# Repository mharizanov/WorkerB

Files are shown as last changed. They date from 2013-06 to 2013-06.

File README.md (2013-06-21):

WorkerB
=======

This is my latest project, the “Worker Bee”. It is an ATMega32U4-based Arduino compatible board running at 8Mhz, 
specially designed for low-power battery operation. There is a slot on the board to fit a 2.4Ghz nRF24L01 breakout 
module (not included, optional); Power to that slot is controlled via a MOSFET, so that the MCU is in control and 
can power the nRF24L01 whenever/if necessary and save power.

The board can be powered via a single AAA battery using an optional LTC3525 boost regulator, a CR2032 battery or 
any other 2.6-5.5V source (via the on-board MCP1700 for voltages >3.3V or directly at the VCC in)

http://harizanov.com/product/workerb/

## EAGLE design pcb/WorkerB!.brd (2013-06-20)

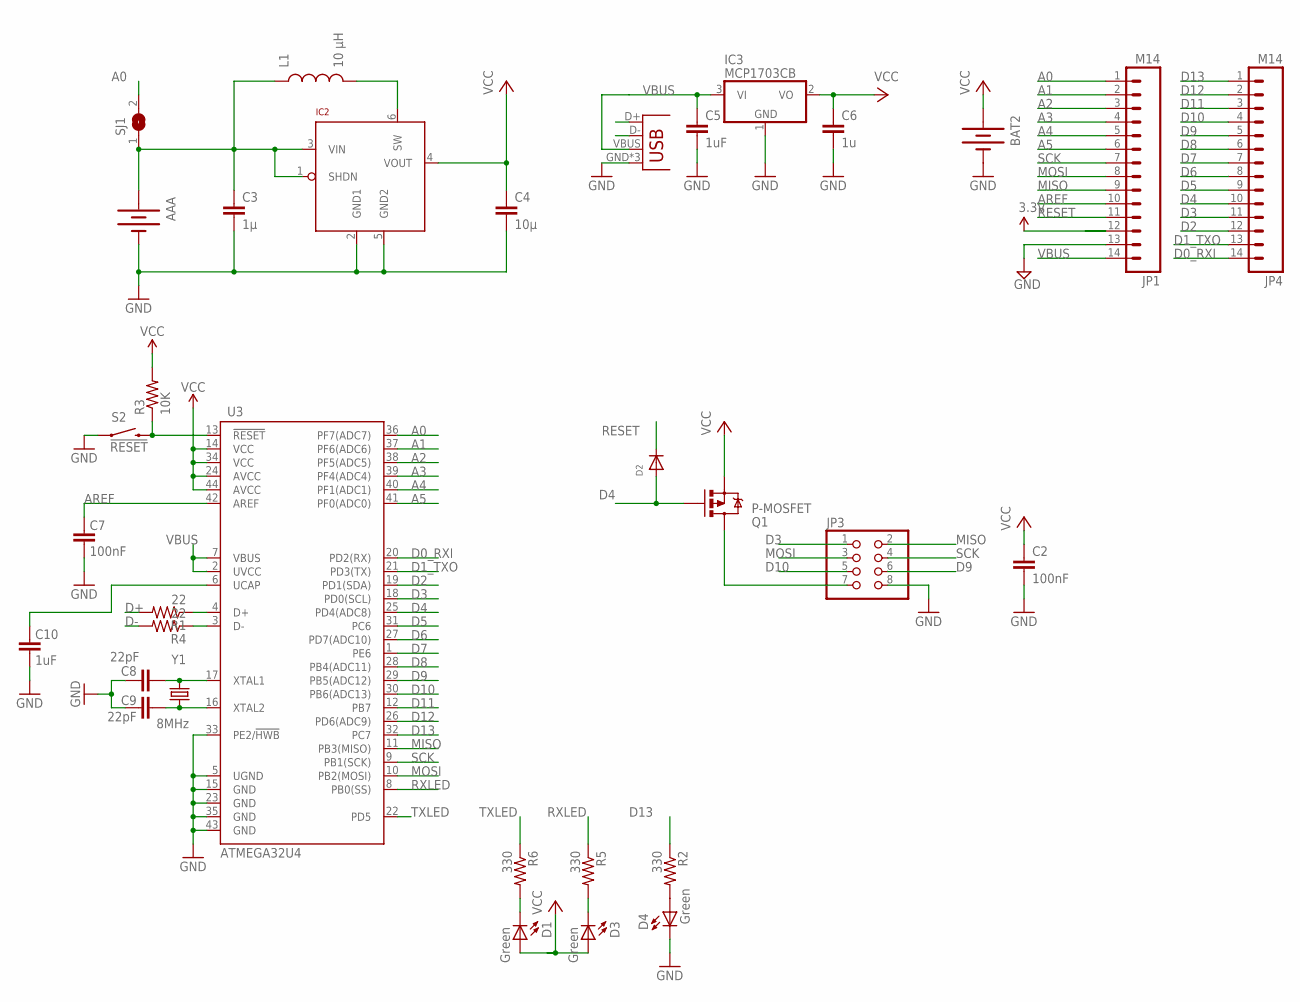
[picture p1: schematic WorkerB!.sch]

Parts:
AAA: BATTERYAAA-JL; BATTERY-AAA-JL
BAT2: BATTERY20PTH; BATTCOM_20MM_PTH
C2: 100nF; C0603K
C3: 1µ; 0603-CAP
C4: 10µ; 0805
C5: 1uF; C0603K
C6: 1u; C0603K
C7: 100nF; 0402-CAP
C8, C9: 22pF; 0402-CAP
C10: 1uF; 0402-CAP
D1, D3, D4: Green; LED-0603
D2: DIODESOD-323F; SOD-323F
IC2: LTC3525; SC70
IC3: MCP1703CB; SOT23
JP1, JP4: M14; 1X14
JP2: USB-MICROB
JP3: PINHD-2X4; 2X04
L1: 10 µH; 1210
Q1: P-MOSFET; SOT23
R1, R4: 22; 0402-RES
R2, R5, R6: 330; 0402-RES
R3: 10K; 0402-RES
S2: !RESET; TACTILE_SWITCH_SMD
SJ1: SJ
U3: ATMEGA32U4; QFN-44-NOPAD
Y1: 8MHz; CRYSTAL-SMD-5X3

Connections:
A0: JP1.1, SJ1.2, U3.36 (PF7(ADC7))
A1: JP1.2, U3.37 (PF6(ADC6))
A2: JP1.3, U3.38 (PF5(ADC5))
A3: JP1.4, U3.39 (PF4(ADC4))
A4: JP1.5, U3.40 (PF1(ADC1))
A5: JP1.6, U3.41 (PF0(ADC0))
AREF: C7.2, JP1.10, U3.42 (AREF)
D0_RXI: JP4.14, U3.20 (PD2(RX))
D1_TXO: JP4.13, U3.21 (PD3(TX))
D2: JP4.12, U3.19 (PD1(SDA))
D3: JP3.1, JP4.11, U3.18 (PD0(SCL))
D4: D2.A, JP4.10, Q1.1 (G), U3.25 (PD4(ADC8))
D5: JP4.9, U3.31 (PC6)
D6: JP4.8, U3.27 (PD7(ADC10))
D7: JP4.7, U3.1 (PE6)
D8: JP4.6, U3.28 (PB4(ADC11))
D9: JP3.6, JP4.5, U3.29 (PB5(ADC12))
D10: JP3.5, JP4.4, U3.30 (PB6(ADC13))
D11: JP4.3, U3.12 (PB7)
D12: JP4.2, U3.26 (PD6(ADC9))
D13: JP4.1, R2.1, U3.32 (PC7)
D+: JP2.D+, R1.2
D-: JP2.D-, R4.2
GND: AAA.GND@1 (-), BAT2.2 (-), C2.2, C3.2, C4.2, C5.2, C6.2, C7.1, C8.2, C9.2, C10.1, D4.C, IC2.2 (GND1), IC2.5 (GND2), IC3.1 (GND), JP1.13, JP2.GND, JP2.MT1 (GND), JP2.MT2 (GND), JP3.8, S2.1, U3.5 (UGND), U3.15 (GND), U3.23 (GND), U3.33 (PE2/!HWB), U3.35 (GND), U3.43 (GND)
MISO: JP1.9, JP3.2, U3.11 (PB3(MISO))
MOSI: JP1.8, JP3.3, U3.10 (PB2(MOSI))
unnamed: C9.1, U3.16 (XTAL2), Y1.1
unnamed: R1.1, U3.4 (D+)
unnamed: D4.A, R2.2
unnamed: C8.1, U3.17 (XTAL1), Y1.3 (2)
unnamed: C10.2, U3.6 (UCAP)
unnamed: D3.C, R5.2
unnamed: R4.1, U3.3 (D-)
unnamed: D1.C, R6.2
unnamed: JP3.7, Q1.3 (D)
unnamed: IC2.6 (SW), L1.2
RESET: D2.C, JP1.11, R3.1, S2.3 (2), U3.13 (!RESET)
RXLED: R5.1, U3.8 (PB0(SS))
SCK: JP1.7, JP3.4, U3.9 (PB1(SCK))
TXLED: R6.1, U3.22 (PD5)
VBUS: C5.1, IC3.3 (VI), JP1.14, JP2.VBUS, U3.2 (UVCC), U3.7 (VBUS)
VCC: BAT2.1 (+), C2.1, C4.1, C6.1, D1.A, D3.A, IC2.4 (VOUT), IC3.2 (VO), JP1.12, Q1.2 (S), R3.2, U3.14 (VCC), U3.24 (AVCC), U3.34 (VCC), U3.44 (AVCC)
VIN: AAA.PWR@1 (+), C3.1, IC2.1 (SHDN), IC2.3 (VIN), L1.1, SJ1.1

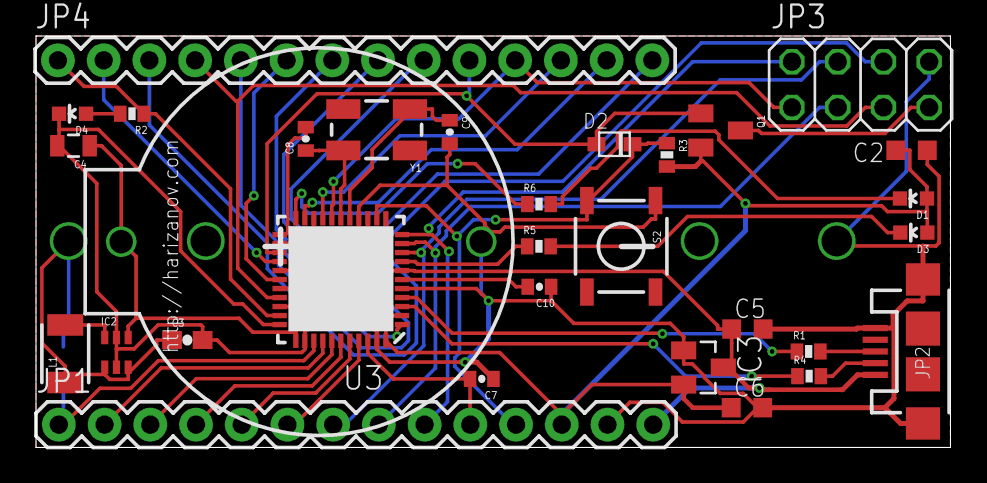
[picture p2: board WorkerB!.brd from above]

Board: 2 copper layers, 50.8 x 22.9 mm, 33 parts (1 on the bottom side), 43 nets.

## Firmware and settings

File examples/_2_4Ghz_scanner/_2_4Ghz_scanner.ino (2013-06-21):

#include <SPI.h>

// Poor Man's Wireless 2.4GHz Scanner
//
// uses an nRF24L01p connected to an Arduino
// 
// Cables are:
//     SS       -> 10
//     MOSI     -> 11
//     MISO     -> 12
//     SCK      -> 13
// 
// and CE       ->  9
//
// created March 2011 by Rolf Henkel
//

#define CE  9
#define CSN 10

// Array to hold Channel data
#define CHANNELS  64
int channel[CHANNELS];

// greyscale mapping 
int  line;
char grey[] = " .:-=+*aRW";

// nRF24L01P registers we need
#define _NRF24_CONFIG      0x00
#define _NRF24_EN_AA       0x01
#define _NRF24_RF_CH       0x05
#define _NRF24_RF_SETUP    0x06
#define _NRF24_RPD         0x09

// get the value of a nRF24L01p register
byte getRegister(byte r)
{
  byte c;
  
  digitalWrite(CSN,LOW);
  c = SPI.transfer(r&0x1F);
  c = SPI.transfer(0);  
  digitalWrite(CSN,HIGH);

  return(c);
}

// set the value of a nRF24L01p register
void setRegister(byte r, byte v)
{
  digitalWrite(CSN,LOW);
  SPI.transfer((r&0x1F)|0x20);
  SPI.transfer(v);
  digitalWrite(CSN,HIGH);
}
  
// power up the nRF24L01p chip
void powerUp(void)
{
  setRegister(_NRF24_CONFIG,getRegister(_NRF24_CONFIG)|0x02);
  delayMicroseconds(130);
}

// switch nRF24L01p off
void powerDown(void)
{
  setRegister(_NRF24_CONFIG,getRegister(_NRF24_CONFIG)&~0x02);
}

// enable RX 
void enable(void)
{
      digitalWrite(CE,HIGH);
}

// disable RX
void disable(void)
{
  digitalWrite(CE,LOW);
}

// setup RX-Mode of nRF24L01p
void setRX(void)
{
  setRegister(_NRF24_CONFIG,getRegister(_NRF24_CONFIG)|0x01);
  enable();
  // this is slightly shorter than
  // the recommended delay of 130 usec
  // - but it works for me and speeds things up a little...
  delayMicroseconds(100);
}

// scanning all channels in the 2.4GHz band
void scanChannels(void)
{
  disable();
  for( int j=0 ; j<200  ; j++)
  {
    for( int i=0 ; i<CHANNELS ; i++)
    {
      // select a new channel
      setRegister(_NRF24_RF_CH,(128*i)/CHANNELS);
      
      // switch on RX
      setRX();
      
      // wait enough for RX-things to settle
      delayMicroseconds(40);
      
      // this is actually the point where the RPD-flag
      // is set, when CE goes low
      disable();
      
      // read out RPD flag; set to 1 if 
      // received power > -64dBm
      if( getRegister(_NRF24_RPD)>0 )   channel[i]++;
    }
  }
}

// outputs channel data as a simple grey map
void outputChannels(void)
{
  int norm = 0;
  
  // find the maximal count in channel array
  for( int i=0 ; i<CHANNELS ; i++)
    if( channel[i]>norm ) norm = channel[i];
    
  // now output the data
  Serial.print('|');
  for( int i=0 ; i<CHANNELS ; i++)
  {
    int pos;
    
    // calculate grey value position
    if( norm!=0 ) pos = (channel[i]*10)/norm;
    else          pos = 0;
    
    // boost low values
    if( pos==0 && channel[i]>0 ) pos++;
    
    // clamp large values
    if( pos>9 ) pos = 9;
   
    // print it out
    Serial.print(grey[pos]);
    channel[i] = 0;
  }
  
  // indicate overall power
  Serial.print("| ");
  Serial.println(norm);
}

// give a visual reference between WLAN-channels and displayed data
void printChannels(void)
{
  // output approximate positions of WLAN-channels
  Serial.println(">      1 2  3 4  5  6 7 8  9 10 11 12 13  14                     <");
}

void setup()
{
  delay(5000);
  Serial.begin(57600);
  pinMode(4,OUTPUT);
  digitalWrite(4,LOW);
  
  Serial.println("Starting Poor Man's Wireless 2.4GHz Scanner ...");
  Serial.println();

  // Channel Layout
  // 0         1         2         3         4         5         6
  // 0123456789012345678901234567890123456789012345678901234567890123
  //       1 2  3 4  5  6 7 8  9 10 11 12 13  14                     | 
  //
  Serial.println("Channel Layout");
  printChannels();
  
  // Setup SPI
  SPI.begin();
  SPI.setDataMode(SPI_MODE0);
  SPI.setClockDivider(SPI_CLOCK_DIV2);
  SPI.setBitOrder(MSBFIRST);
  
  // Activate Chip Enable
  pinMode(CE,OUTPUT);
  pinMode(CSN,OUTPUT);    //CS
  disable();
  
  // now start receiver
  powerUp();
  
  // switch off Shockburst
  setRegister(_NRF24_EN_AA,0x0);
  
  // make sure RF-section is set properly 
  // - just write default value... 
  setRegister(_NRF24_RF_SETUP,0x0F); 
  
  // reset line counter
  line = 0;
}

void loop() 
{ 
  // do the scan
  scanChannels();
  
  // output the result
  outputChannels();
  
  // output WLAN-channel reference every 12th line
  if( line++>12 )
  {
    printChannels();
    line = 0;
  }
}

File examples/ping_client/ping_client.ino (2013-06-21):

/**
 * A Mirf example to test the latency between two Ardunio.
 *
 * Pins:
 * Hardware SPI:
 * MISO -> 12
 * MOSI -> 11
 * SCK -> 13
 *
 * Configurable:
 * CE -> 8
 * CSN -> 7
 *
 * Note: To see best case latency comment out all Serial.println
 * statements not displaying the result and load 
 * 'ping_server_interupt' on the server.
 */

#include <SPI.h>
#include <Mirf.h>
#include <nRF24L01.h>
#include <MirfHardwareSpiDriver.h>

#define LEDPin 13

void setup(){
  Serial.begin(9600);
  
  pinMode(4,OUTPUT);
  digitalWrite(4,LOW);  //Turn on the nRF24L01
  delay(6000);


  /*
   * Setup pins / SPI.
   */
   
  /* To change CE / CSN Pins:
   * 
   * Mirf.csnPin = 9;
   * Mirf.cePin = 7;
   */
  
  Mirf.cePin = 9;
  Mirf.csnPin = 10;
  
  Mirf.spi = &MirfHardwareSpi;
  Mirf.init();
  
  /*
   * Configure reciving address.
   */
   
  Mirf.setRADDR((byte *)"clie1");
  
  /*
   * Set the payload length to sizeof(unsigned long) the
   * return type of millis().
   *
   * NB: payload on client and server must be the same.
   */
   
  Mirf.payload = sizeof(unsigned long);
  Mirf.channel = 8;
  
  /*
   * Write channel and payload config then power up reciver.
   */
   
  /*
   * To change channel:
   * 
   * Mirf.channel = 10;
   *
   * NB: Make sure channel is legal in your area.
   */
   
  Mirf.config();
     // Set 1Mbps data rate
//   Mirf.configRegister(RF_SETUP,0x06);

    //Mirf.configRegister(RF_SETUP, 0b00100110);
    //Mirf.configRegister(SETUP_RETR, 0b00011111);


   
  Serial.println("Beginning ... "); 
}

void loop(){
  unsigned long time = millis();
  
  Mirf.setTADDR((byte *)"serv1");

  pinMode(LEDPin,OUTPUT);
  digitalWrite(LEDPin,HIGH);
 
  Mirf.send((byte *)&time);
  
  while(Mirf.isSending()){
  }
 
 digitalWrite(LEDPin,LOW);
 
  Serial.println("Finished sending");
  delay(10);

  while(!Mirf.dataReady()){
    //Serial.println("Waiting");
    if ( ( millis() - time ) > 1000 ) {
      Serial.println("Timeout on response from server!");
      return;
    }
  }
  
  Mirf.getData((byte *) &time);


  
  Serial.print("Ping: ");
  Serial.println((millis() - time));

  
  delay(1000);
} 
  
  
  

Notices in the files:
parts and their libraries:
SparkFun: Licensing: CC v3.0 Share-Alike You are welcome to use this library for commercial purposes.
